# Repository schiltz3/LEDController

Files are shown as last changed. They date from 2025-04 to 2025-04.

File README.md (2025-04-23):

# Power Distribution Board Screenshots
Schematic:
[LEDControllerPDB/Outputs/LED Power Distribution Board sch.pdf](https://github.com/schiltz3/LEDController/blob/ab43750f7913fe42482215626bbdc119c35f3c25/LEDControllerPDB/Outputs/LED%20Power%20Distribution%20Board%20sch.pdf)
Front:
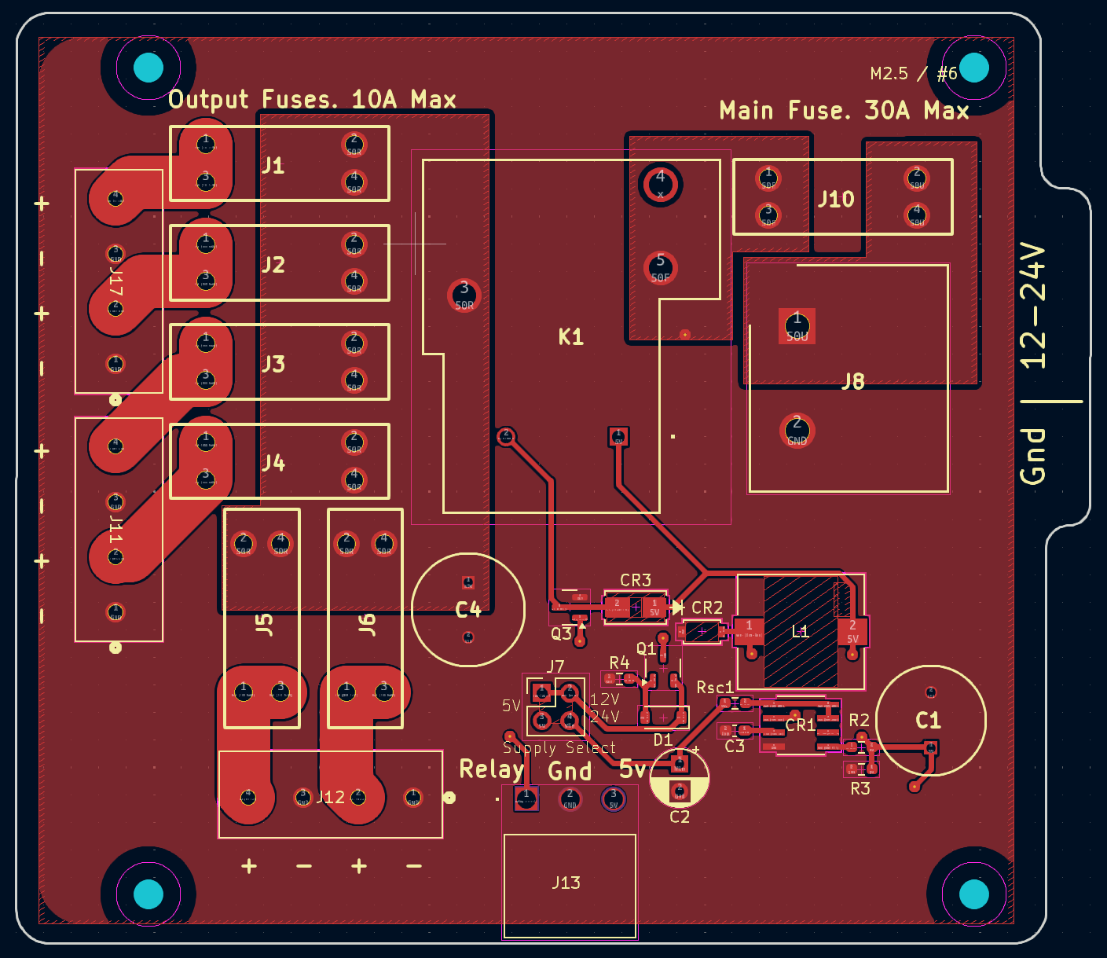
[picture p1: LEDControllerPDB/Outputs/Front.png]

Back:
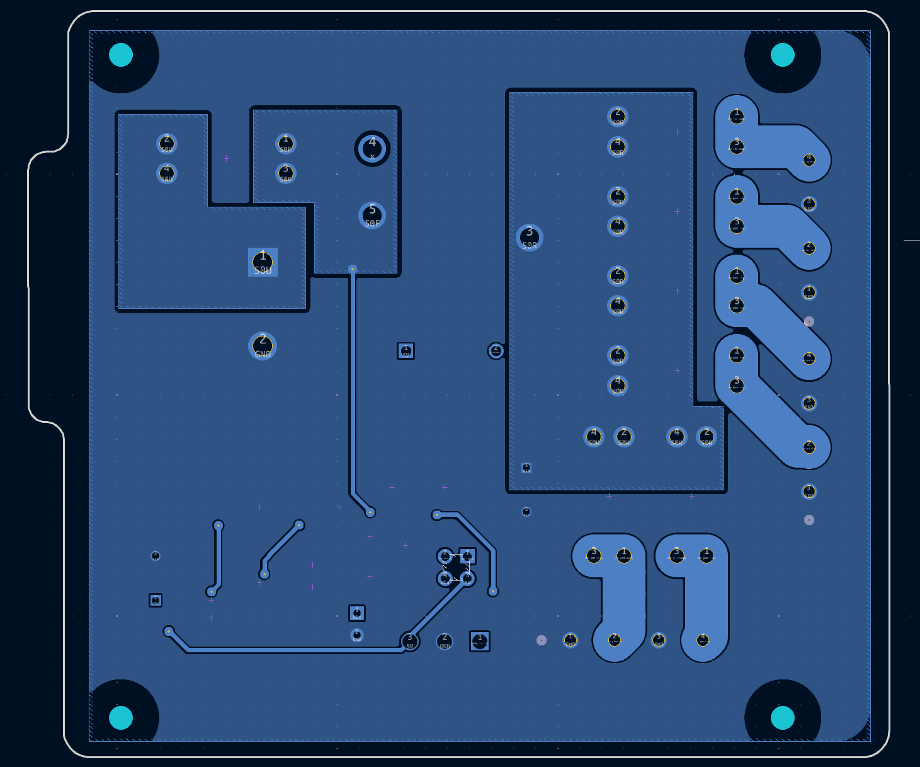
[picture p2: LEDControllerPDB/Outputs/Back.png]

All:
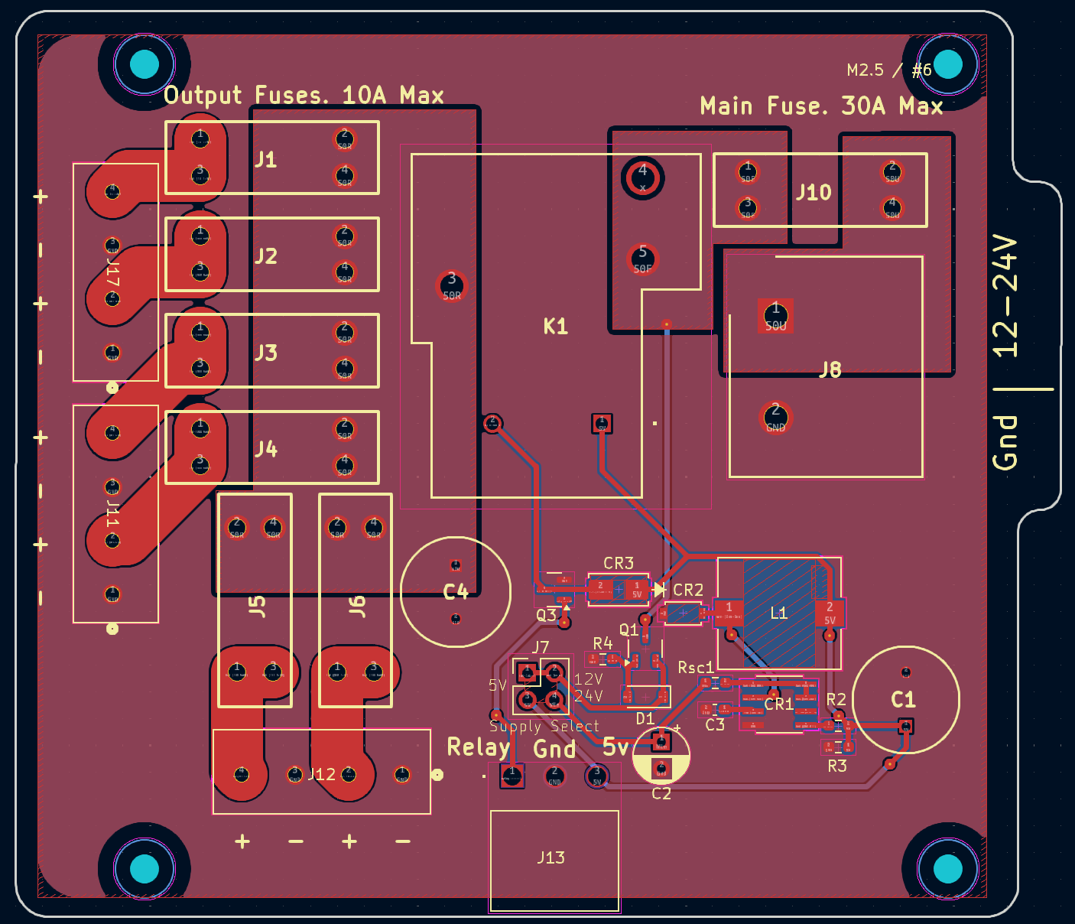
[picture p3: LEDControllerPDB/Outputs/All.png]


# Controll Board
Schematic:
[LEDControllerBrain/Outputs/LED Control Board sch.pdf](https://github.com/schiltz3/LEDController/blob/master/LEDControllerBrain/Outputs/LED%20Control%20Board%20sch.pdf)
Front:
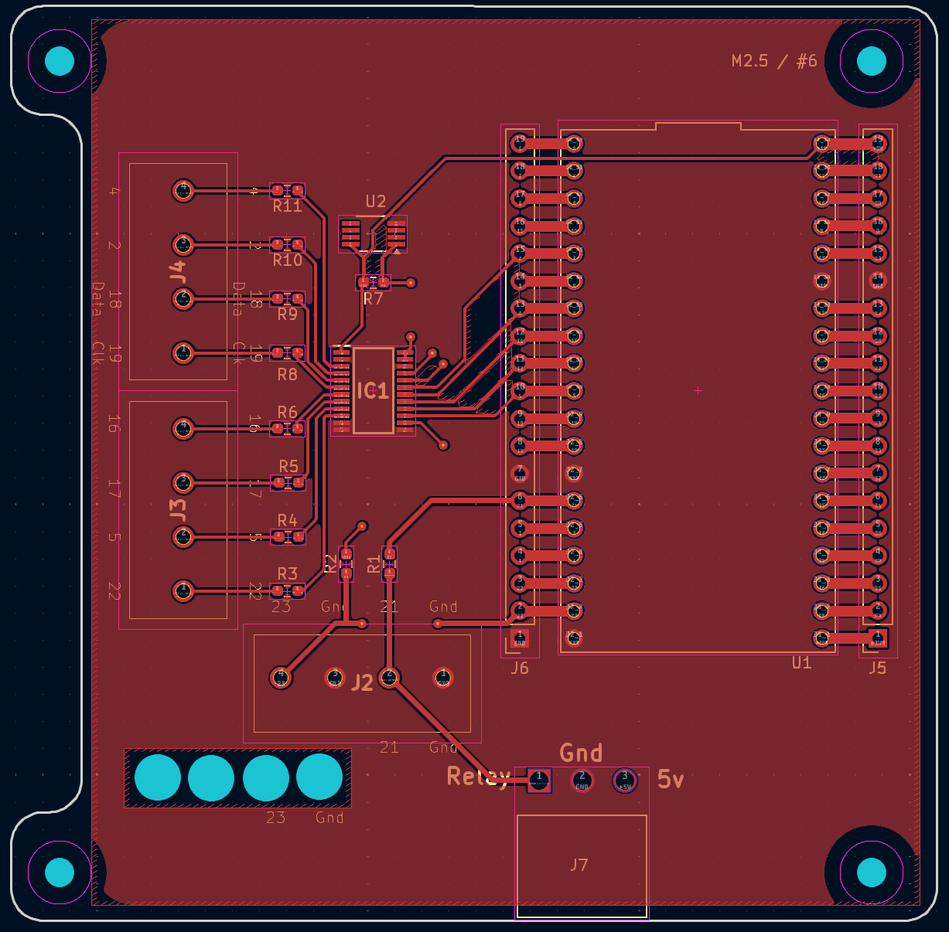
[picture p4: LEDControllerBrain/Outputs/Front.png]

Back:
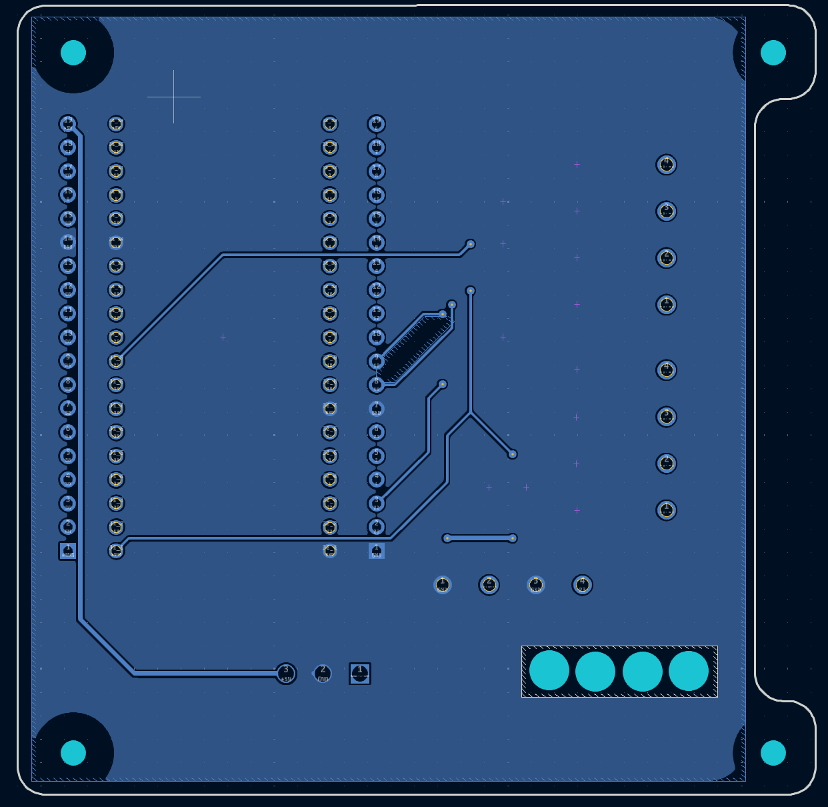
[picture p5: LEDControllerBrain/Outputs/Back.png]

All:
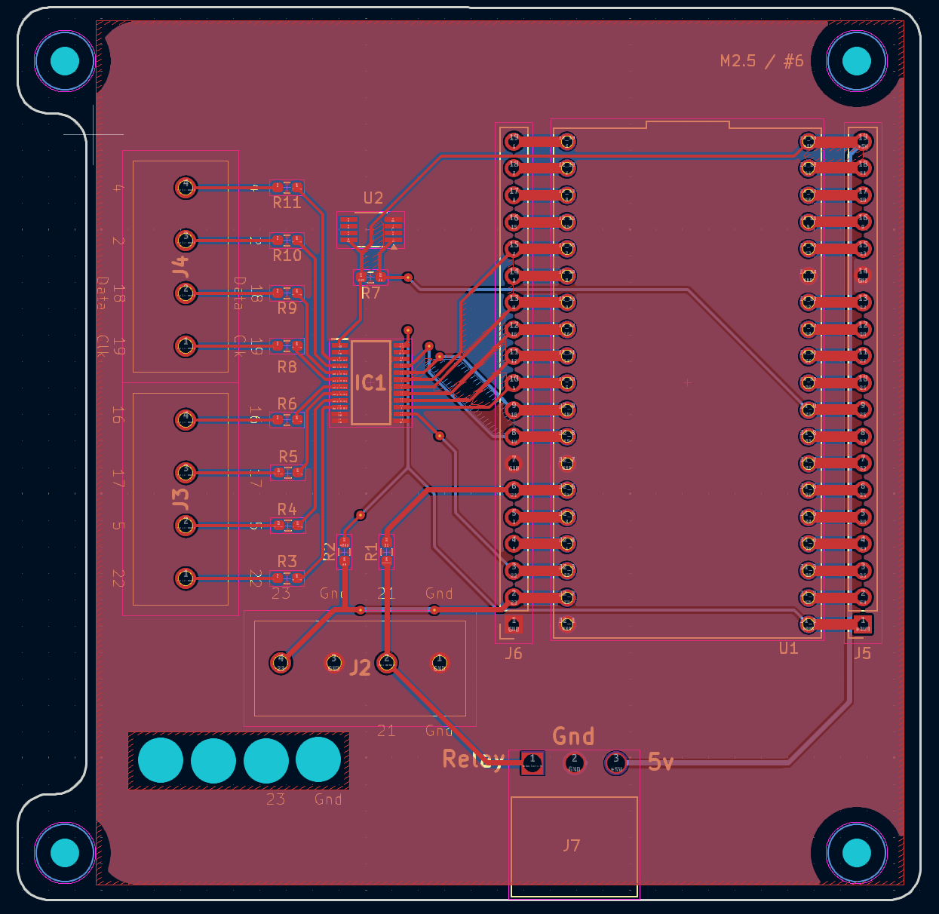
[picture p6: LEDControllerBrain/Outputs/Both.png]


# Assemmbly 
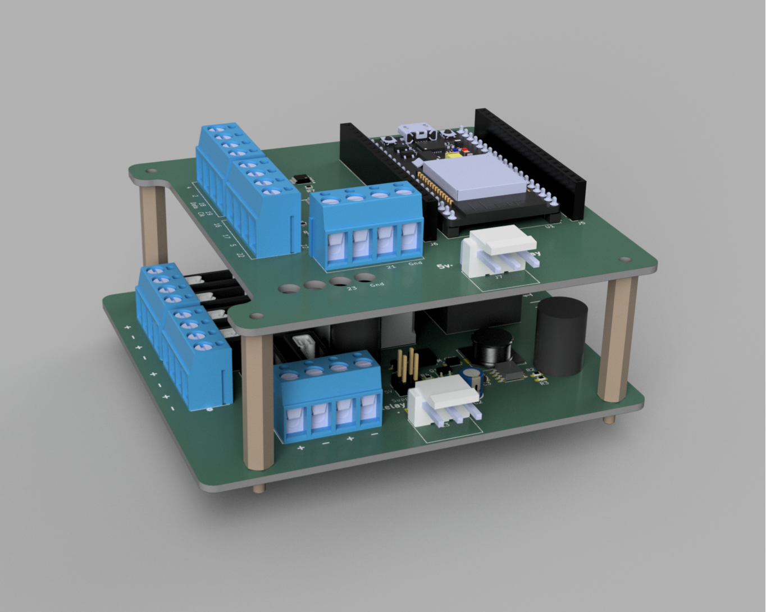
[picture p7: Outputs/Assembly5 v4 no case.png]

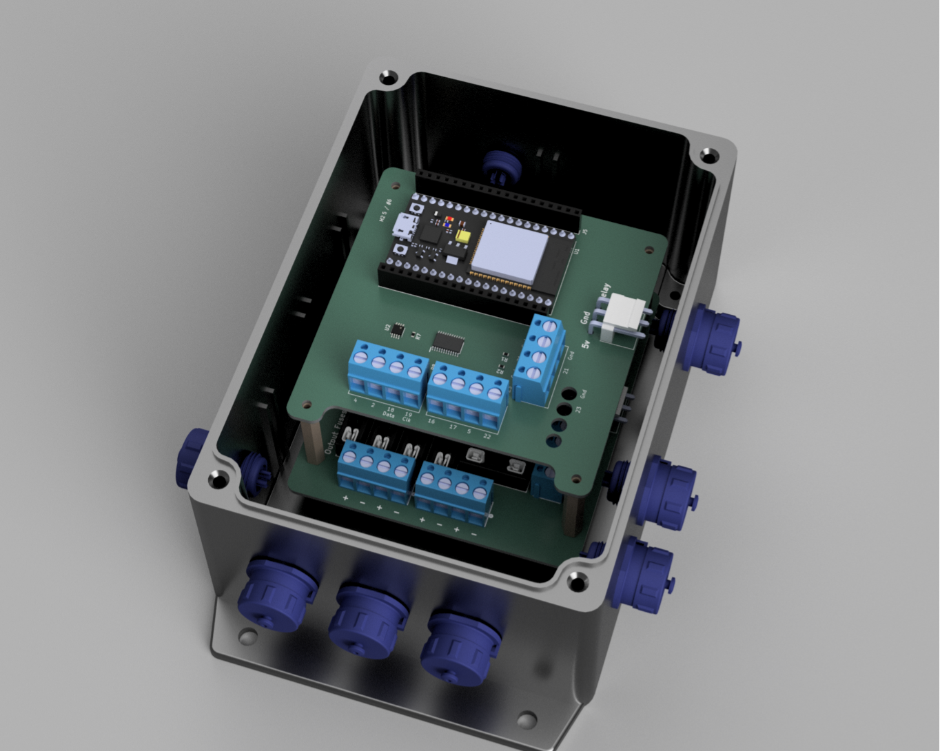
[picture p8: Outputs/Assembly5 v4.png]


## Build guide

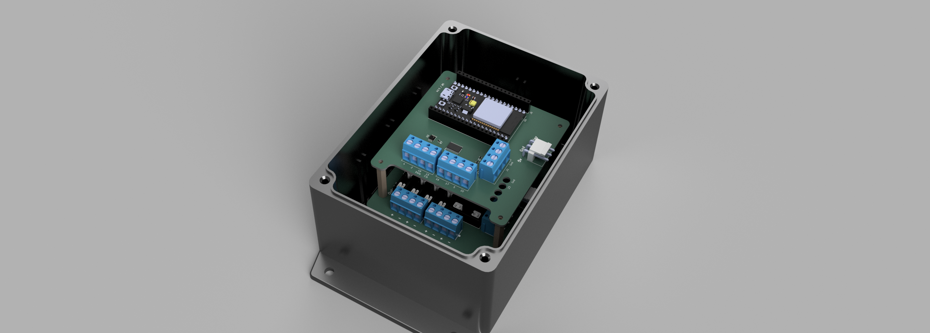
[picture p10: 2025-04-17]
LEDControllerBrain/Assembly5 v2.png

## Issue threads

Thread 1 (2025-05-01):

V2 improvements

schiltz3, 2025-05-01:
* Move to 1206 components
* Move to 1 fuse for 2 outputs
* Smaller bulk capacitor
* Smaller relay / remove relay and add a scheme for switching before the regulator
* Add test points to make reworking/testing IC's easier
* Smaller inter-pcb connectors

schiltz3, 2025-05-13:
Add a supervisor to the microcontroller to help it boot when the regulator has a bad slew rate

https://www.digikey.com/en/products/detail/texas-instruments/TLV809I50DBZR/2696416

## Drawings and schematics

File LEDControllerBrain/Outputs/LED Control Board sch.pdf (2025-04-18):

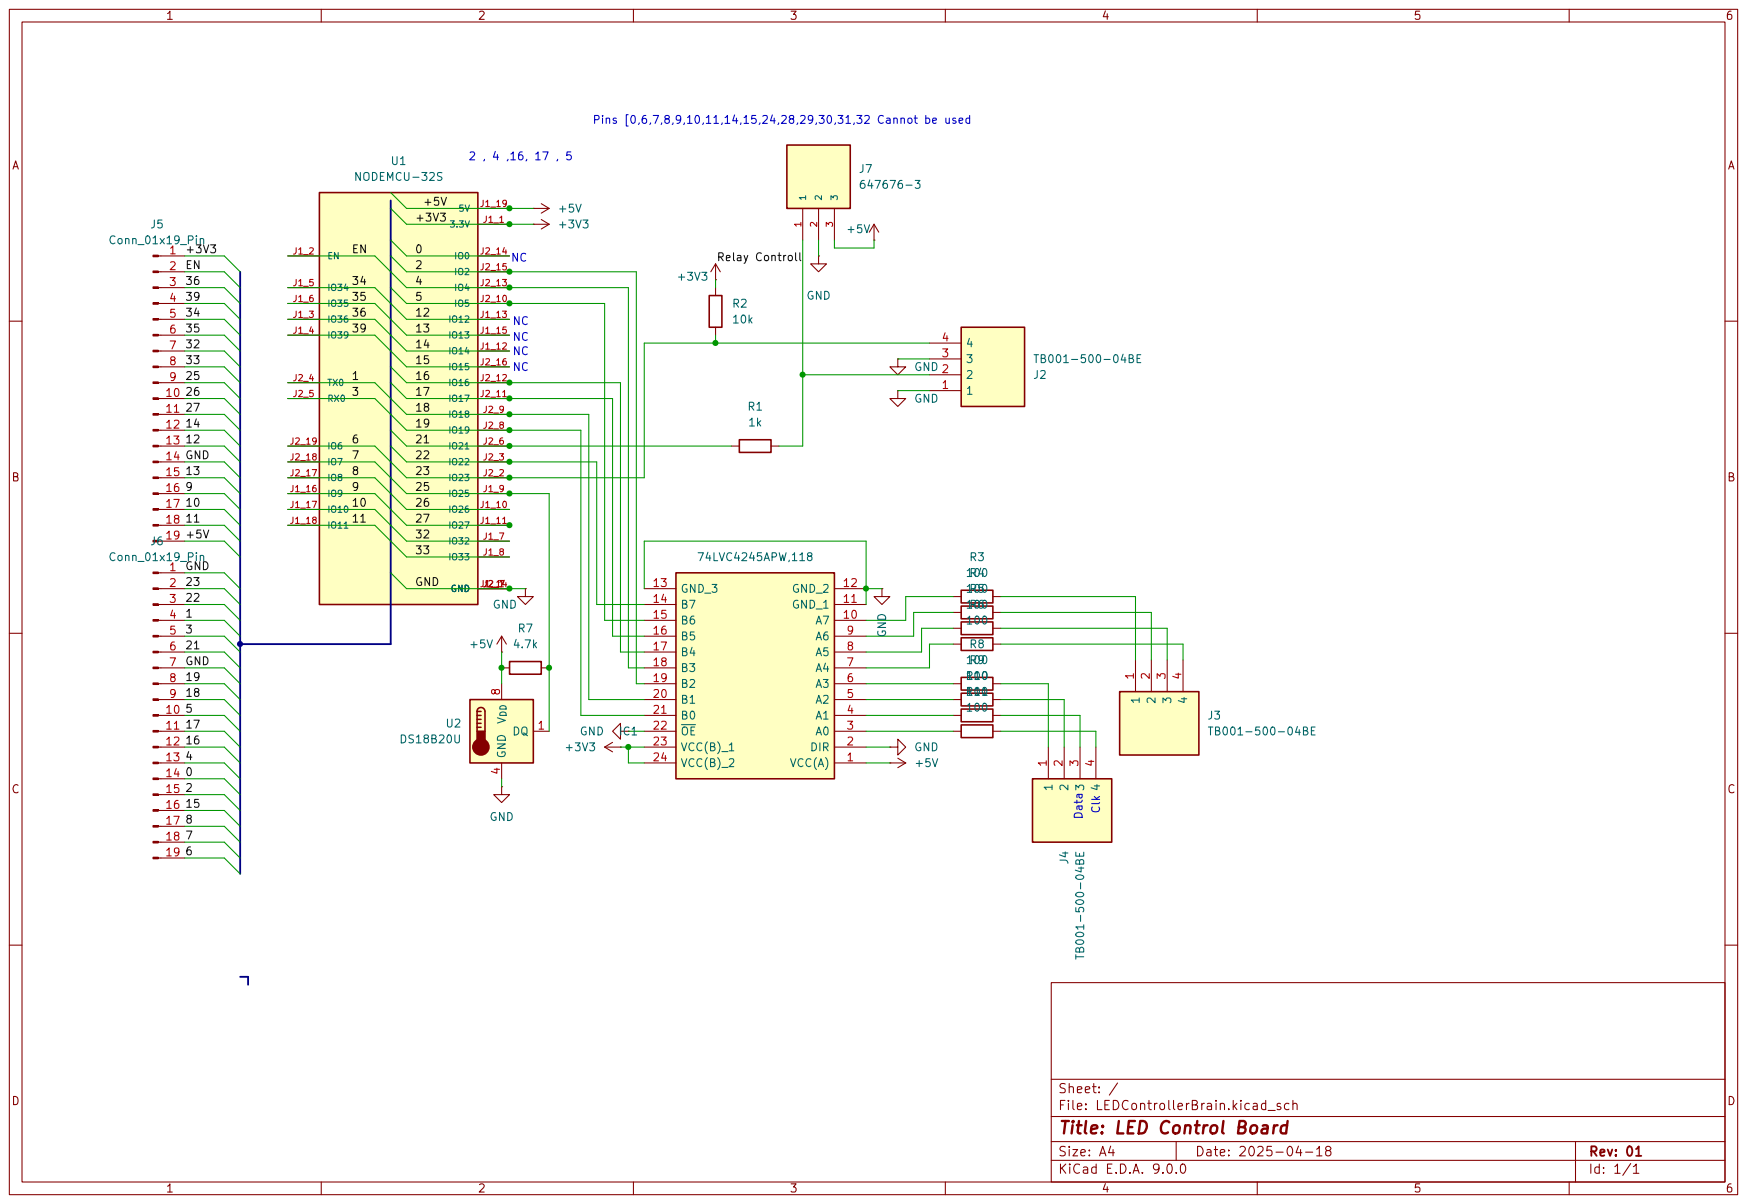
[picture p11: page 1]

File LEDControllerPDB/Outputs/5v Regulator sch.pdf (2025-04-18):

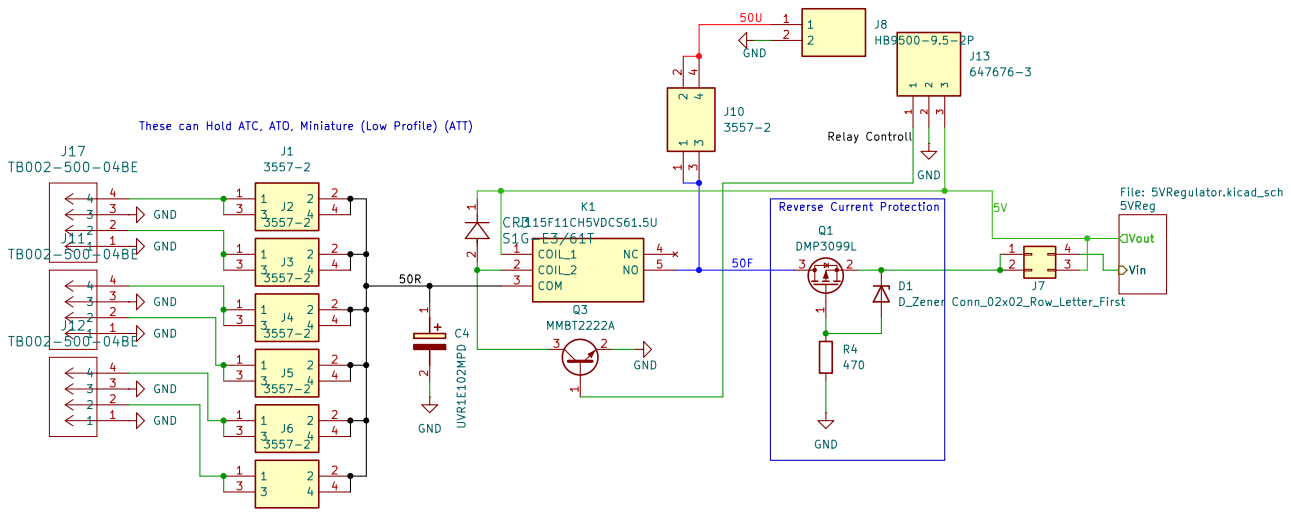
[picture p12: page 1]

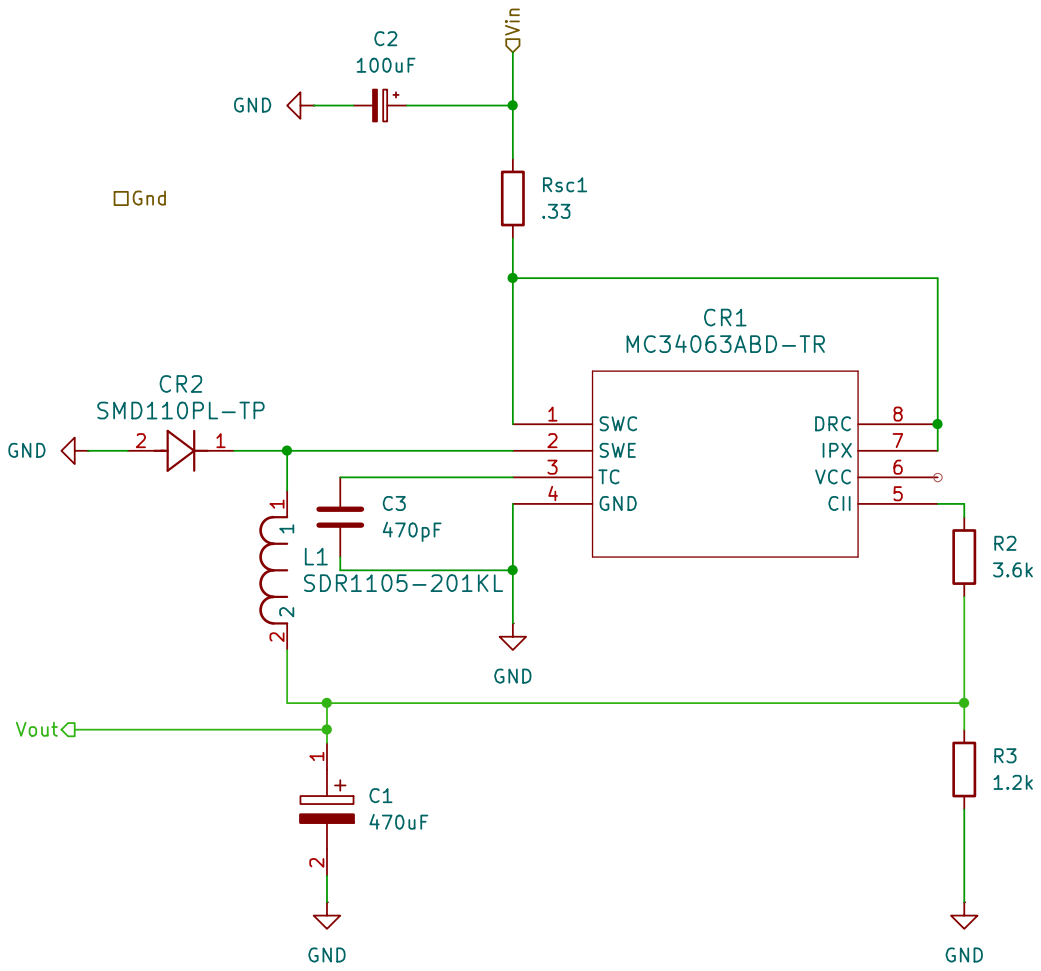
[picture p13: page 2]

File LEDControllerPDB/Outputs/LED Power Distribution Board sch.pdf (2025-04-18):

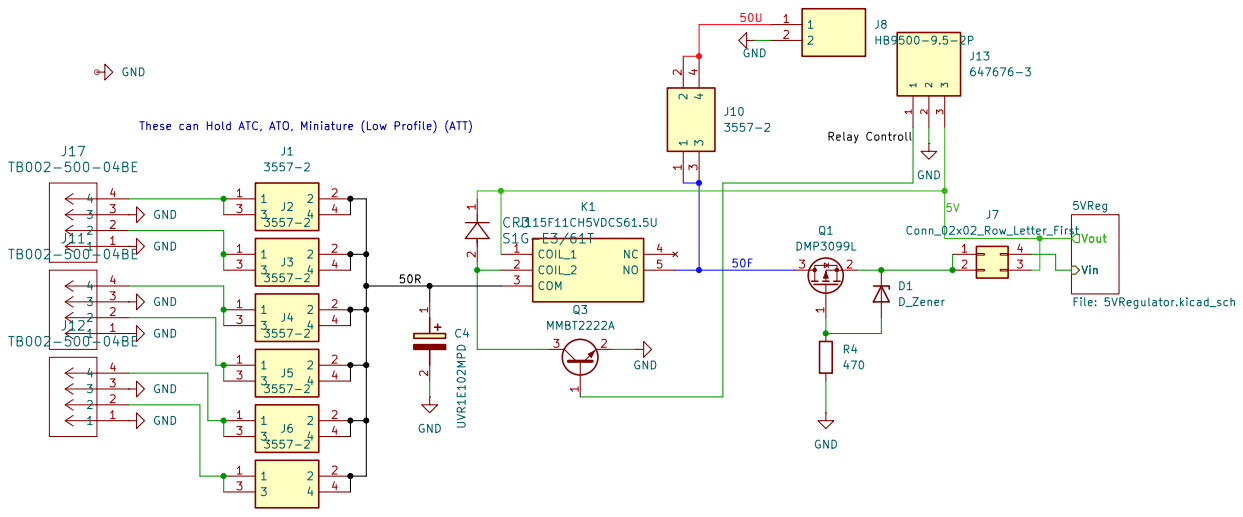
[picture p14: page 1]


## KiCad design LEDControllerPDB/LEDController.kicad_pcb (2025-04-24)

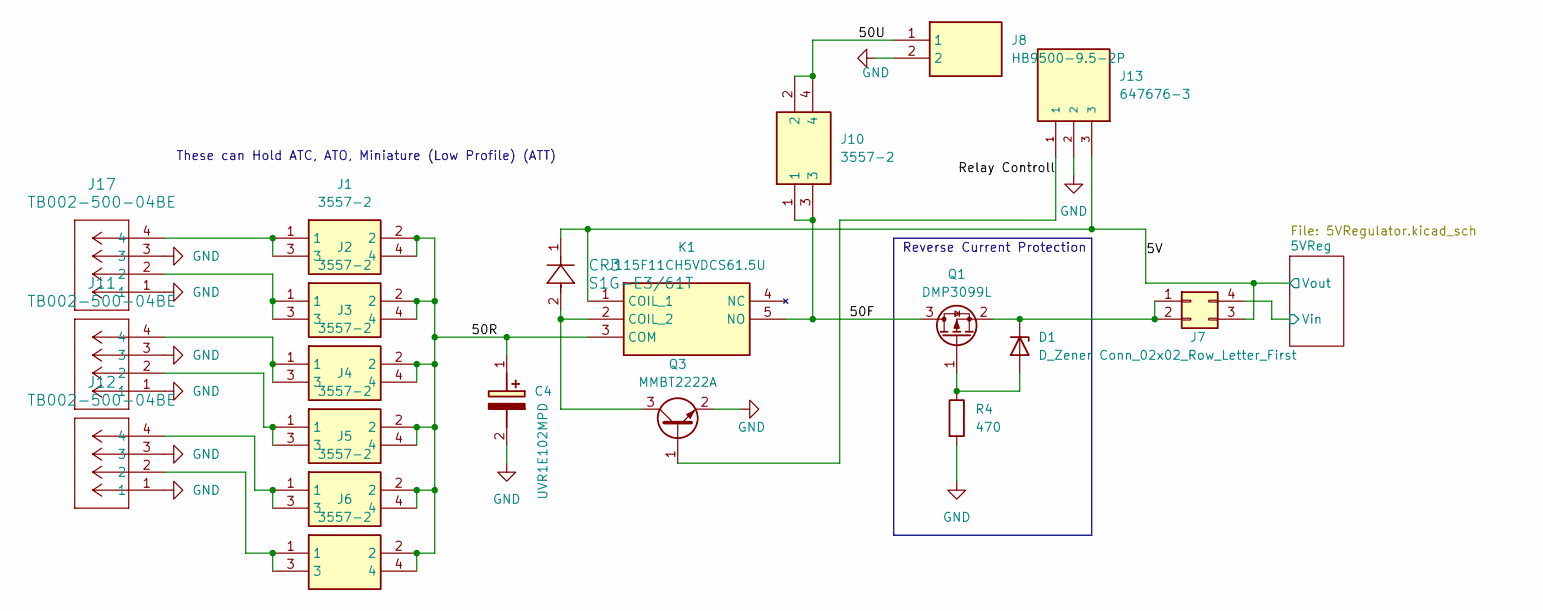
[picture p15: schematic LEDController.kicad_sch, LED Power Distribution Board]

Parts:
C4: UVR1E102MPD; CAPPRD500W60D1025H2200; Manufacturer_Part_Number UVR1E102MPD; Mouser Part Number 647-UVR1E102MPD
CR3: S1G-E3/61T; DIODE_DO214AC
D1: D_Zener; D_SOD-123
J1, J2, J3, J4, J5, J6, J10: 3557-2; Mouser Part Number 534-3557-2
J7: Conn_02x02_Row_Letter_First; PinHeader_2x02_P2.54mm_Vertical
J8: HB9500-9.5-2P; SHDR2W140P0X950_1X2_2055X1800X1440P; Manufacturer_Part_Number HB9500-9.5-2P
J11, J12, J17: TB002-500-04BE; CONN4_TB002-500_787x299_CUD
J13: 647676-3; TE_647676-3; PARTREV R
K1: J115F11CH5VDCS61.5U; J115F11CH5VDCS615U; Manufacturer_Part_Number J115F11CH5VDCS61.5U
Q1: DMP3099L; SOT-23-3
Q3: MMBT2222A; SOT-23
R4: 470; R_0603_1608Metric_Pad0.98x0.95mm_HandSolder

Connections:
/5V: CR3.1, J7.3, J13.3, K1.1 (COIL_1); also elsewhere on the board
/5VReg/Vin: J7.4; also elsewhere on the board
/50F: J10.1, J10.3, K1.5 (NO), Q1.3 (D)
/50R: C4.1 (+), J1.2, J1.4, J2.2, J2.4, J3.2, J3.4, J4.2, J4.4, J5.2, J5.4, J6.2, J6.4, K1.3 (COM)
/50U: J8.1, J10.2, J10.4
/Relay Controll: J13.1, Q3.1 (B)
GND: C4.2 (-), J8.2, J11.1, J11.3, J12.1, J12.3, J13.2, J17.1, J17.3, Q3.2 (E), R4.2; also elsewhere on the board
unnamed: D1.2 (A), Q1.1 (G), R4.1
unnamed: D1.1 (K), J7.1, J7.2, Q1.2 (S)
unnamed: J1.1, J1.3, J17.4
unnamed: J4.1, J4.3, J11.2
unnamed: J3.1, J3.3, J11.4
unnamed: J6.1, J6.3, J12.2
unnamed: J5.1, J5.3, J12.4
unnamed: J2.1, J2.3, J17.2
unnamed: CR3.2, K1.2 (COIL_2), Q3.3 (C)

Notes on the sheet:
Reverse Current Protection
These can Hold ATC, ATO, Miniature (Low Profile) (ATT)

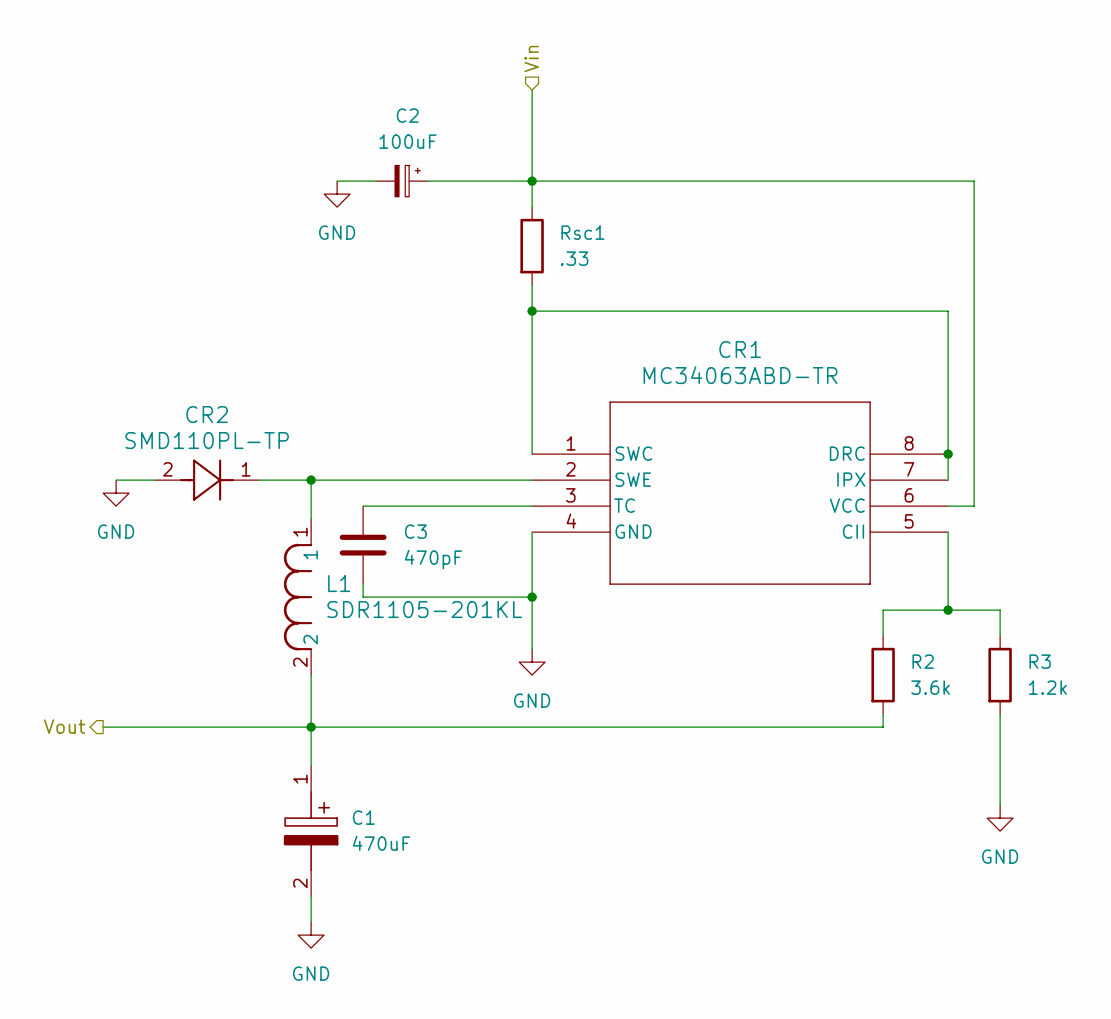
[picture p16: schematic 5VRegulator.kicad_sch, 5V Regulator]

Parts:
C1: 470uF; CAPPRD500W60D1000H1350; Manufacturer_Part_Number ESK477M025AH1EA; Mouser Part Number 80-ESK477M025AH1EA
C2: 100uF; CP_Radial_D5.0mm_P2.50mm
C3: 470pF; C_0603_1608Metric_Pad1.08x0.95mm_HandSolder
CR1: MC34063ABD-TR; SO-8_STM
CR2: SMD110PL-TP; SOD-123FL_MCC
L1: SDR1105-201KL; IND_BOURNS_SDR1105
R2: 3.6k; R_0603_1608Metric_Pad0.98x0.95mm_HandSolder
R3: 1.2k; R_0603_1608Metric_Pad0.98x0.95mm_HandSolder
Rsc1: .33; R_0603_1608Metric_Pad0.98x0.95mm_HandSolder

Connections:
/5V: C1.1, L1.2, R2.2; also elsewhere on the board
/5VReg/Vin: C2.1, CR1.6 (VCC), Rsc1.1; also elsewhere on the board
GND: C1.2, C2.2, C3.2, CR1.4 (GND), CR2.2, R3.2; also elsewhere on the board
unnamed: CR1.5 (CII), R2.1, R3.1
unnamed: CR1.1 (SWC), CR1.7 (IPX), CR1.8 (DRC), Rsc1.2
unnamed: CR1.2 (SWE), CR2.1, L1.1
unnamed: C3.1, CR1.3 (TC)

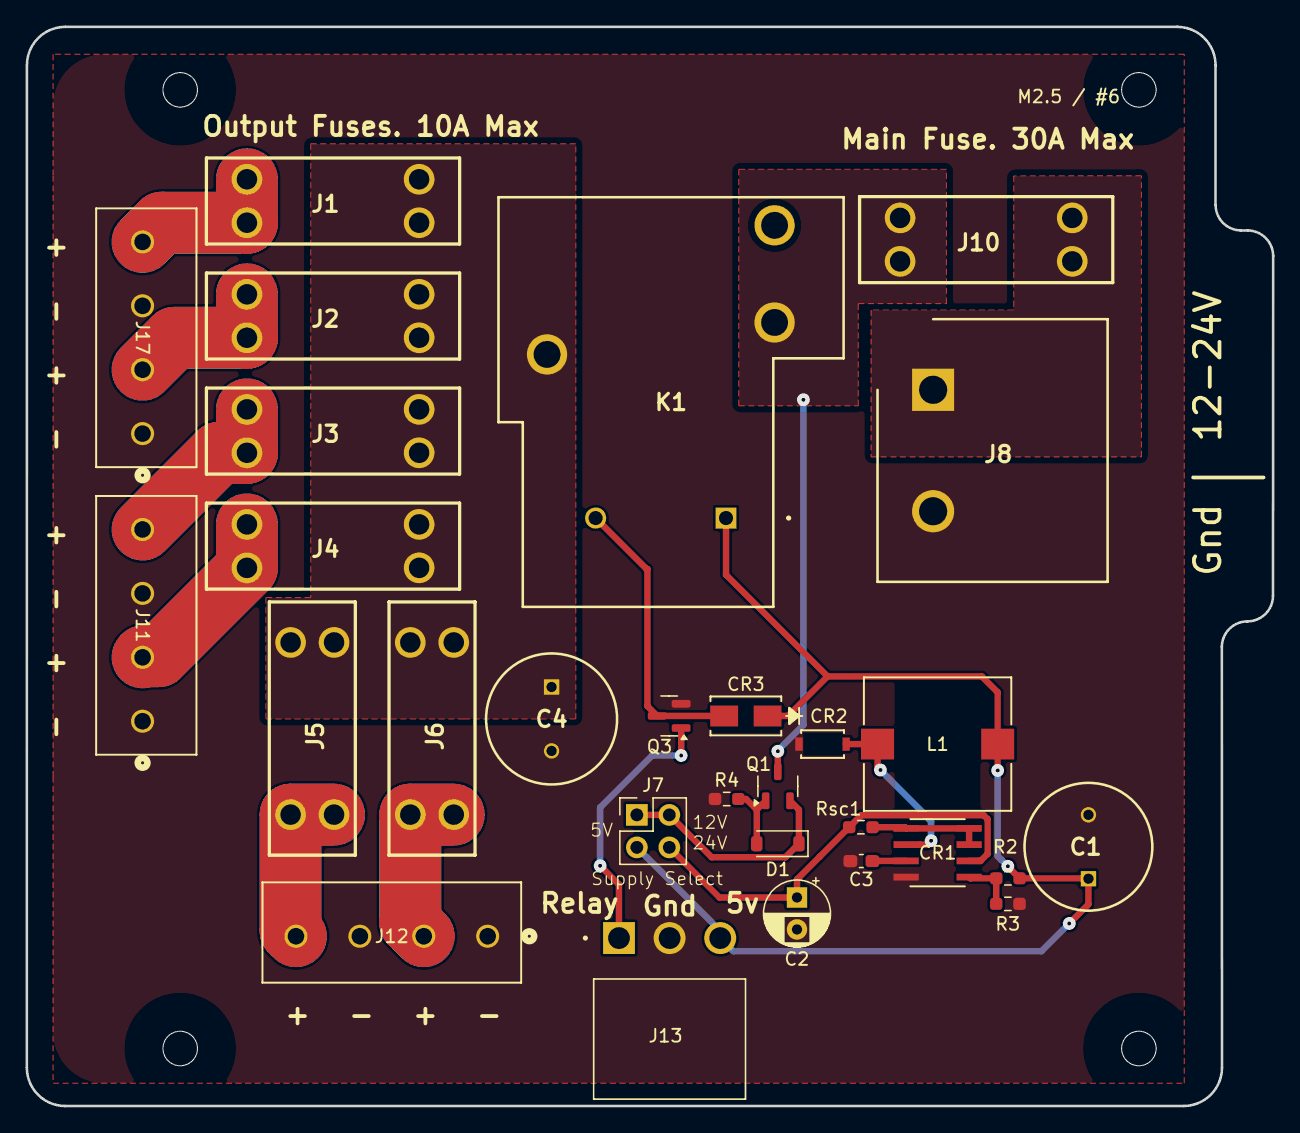
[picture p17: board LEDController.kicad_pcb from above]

Board: 2 copper layers, 97.5 x 84.4 mm, 30 parts (0 on the bottom side), 20 nets.

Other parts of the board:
M2.5 / #6: MountingHole_2.7mm_M2.5

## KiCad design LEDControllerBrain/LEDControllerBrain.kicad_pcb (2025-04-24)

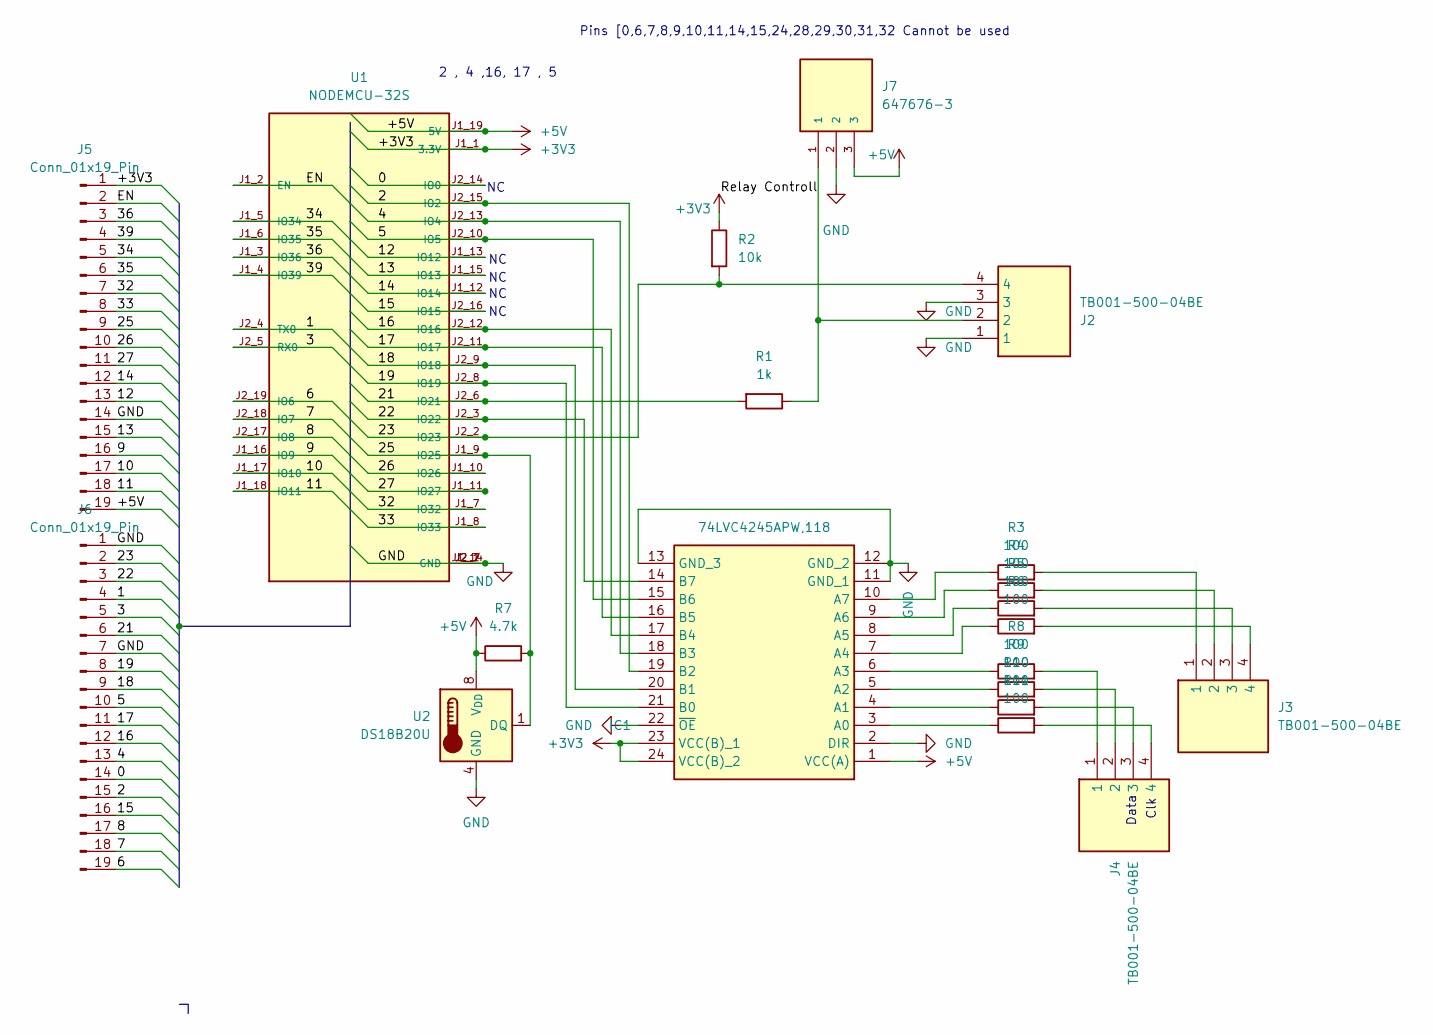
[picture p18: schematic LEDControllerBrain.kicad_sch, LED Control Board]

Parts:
IC1: 74LVC4245APW,118; SOP65P640X110-24N; Manufacturer_Part_Number 74LVC4245APW,118; Mouser Part Number 771-74LVC4245APW-T
J2, J3, J4: TB001-500-04BE; TB00150004BE; Manufacturer_Part_Number TB001-500-04BE
J5, J6: Conn_01x19_Pin; PinSocket_1x19_P2.54mm_Vertical
J7: 647676-3; TE_647676-3; PARTREV R
R1: 1k; R_0603_1608Metric_Pad0.98x0.95mm_HandSolder
R2: 10k; R_0603_1608Metric_Pad0.98x0.95mm_HandSolder
R3, R4, R5, R6, R8, R9, R10, R11: 100; R_0603_1608Metric_Pad0.98x0.95mm_HandSolder
R7: 4.7k; R_0603_1608Metric_Pad0.98x0.95mm_HandSolder
U1: NODEMCU-32S; MODULE_NODEMCU-32S; PARTREV V1
U2: DS18B20U; MSOP-8_3x3mm_P0.65mm

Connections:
+5V: IC1.1 (VCC(A)), J5.19, J7.3, R7.1, U1.J1_19 (5V), U2.8 (V_{DD})
/0: J6.14, U1.J2_14 (IO0)
/1: J6.4, U1.J2_4 (TX0)
/2: IC1.19 (B2), J6.15, U1.J2_15 (IO2)
/3: J6.5, U1.J2_5 (RX0)
/4: IC1.18 (B3), J6.13, U1.J2_13 (IO4)
/5: IC1.15 (B6), J6.10, U1.J2_10 (IO5)
/6: J6.19, U1.J2_19 (IO6)
/7: J6.18, U1.J2_18 (IO7)
/8: J6.17, U1.J2_17 (IO8)
/9: J5.16, U1.J1_16 (IO9)
/10: J5.17, U1.J1_17 (IO10)
/11: J5.18, U1.J1_18 (IO11)
/12: J5.13, U1.J1_13 (IO12)
/13: J5.15, U1.J1_15 (IO13)
/14: J5.12, U1.J1_12 (IO14)
/15: J6.16, U1.J2_16 (IO15)
/16: IC1.17 (B4), J6.12, U1.J2_12 (IO16)
/17: IC1.16 (B5), J6.11, U1.J2_11 (IO17)
/18: IC1.20 (B1), J6.9, U1.J2_9 (IO18)
/19: IC1.21 (B0), J6.8, U1.J2_8 (IO19)
/21: J6.6, R1.2, U1.J2_6 (IO21)
/22: IC1.14 (B7), J6.3, U1.J2_3 (IO22)
/25: J5.9, R7.2, U1.J1_9 (IO25), U2.1 (DQ)
/26: J5.10, U1.J1_10 (IO26)
/27: J5.11, U1.J1_11 (IO27)
/32: J5.7, U1.J1_7 (IO32)
/33: J5.8, U1.J1_8 (IO33)
/34: J5.5, U1.J1_5 (IO34)
/35: J5.6, U1.J1_6 (IO35)
/36: J5.3, U1.J1_3 (IO36)
/39: J5.4, U1.J1_4 (IO39)
/EN: J5.2, U1.J1_2 (EN)
/Relay Controll: J2.2, J7.1, R1.1
GND: IC1.2 (DIR), IC1.11 (GND_1), IC1.12 (GND_2), IC1.13 (GND_3), IC1.22 (~OE), J2.1, J2.3, J5.14, J6.1, J6.7, J7.2, U1.J1_14 (GND), U1.J2_1 (GND), U1.J2_7 (GND), U2.4 (GND)
unnamed: IC1.3 (A0), R11.1
unnamed: IC1.4 (A1), R10.1
unnamed: IC1.5 (A2), R9.1
unnamed: IC1.6 (A3), R8.1
unnamed: IC1.7 (A4), R6.1
unnamed: IC1.8 (A5), R5.1
unnamed: IC1.9 (A6), R4.1
unnamed: IC1.10 (A7), R3.1
unnamed: J3.1, R3.2
unnamed: J3.2, R4.2
unnamed: J3.3, R5.2
unnamed: J3.4, R6.2
unnamed: J4.1, R8.2
unnamed: J4.2, R9.2
unnamed: J4.3, R10.2
unnamed: J4.4, R11.2

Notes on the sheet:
Pins [0,6,7,8,9,10,11,14,15,24,28,29,30,31,32 Cannot be used
2 , 4 ,16, 17 , 5
Data
Clk

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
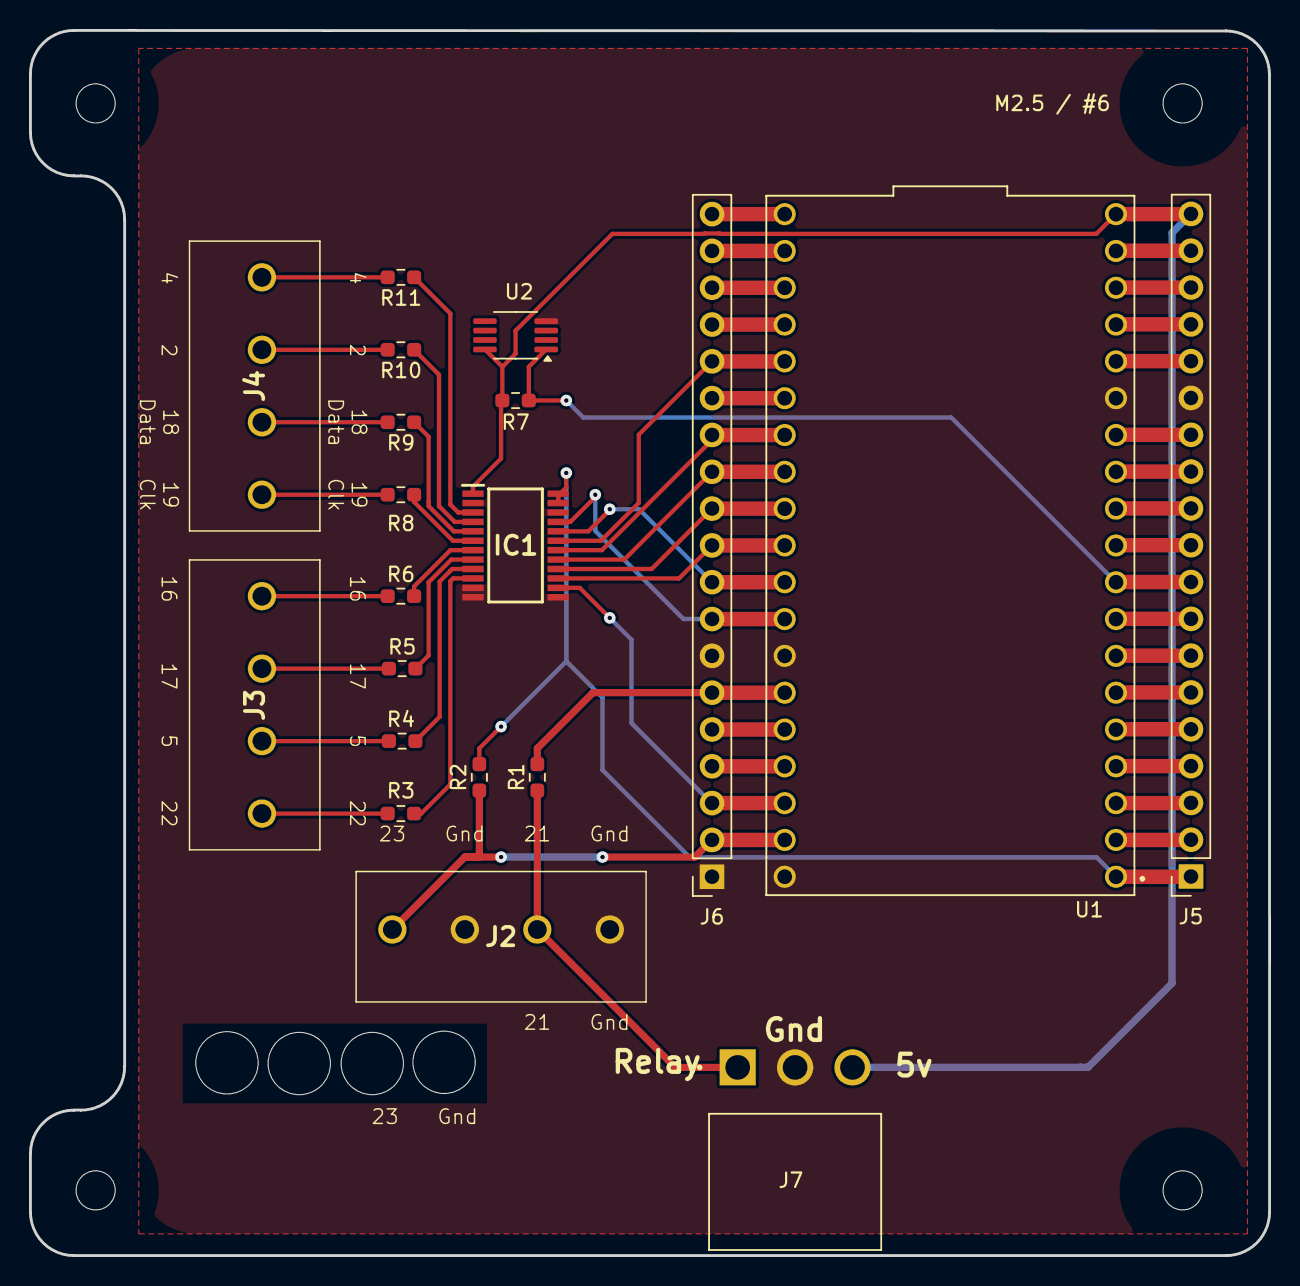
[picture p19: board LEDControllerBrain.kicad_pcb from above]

Board: 2 copper layers, 85.5 x 84.5 mm, 21 parts (0 on the bottom side), 53 nets.

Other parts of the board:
M2.5 / #6: MountingHole_2.7mm_M2.5

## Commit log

2024-12-22 Added diode and transistor
    [LEDController.kicad_pcb, LEDController.kicad_sch]
2024-12-23 Added screw terminals
    [LEDController.kicad_sch]
2024-12-23 updated pcb
    [LEDController.kicad_pcb]
2024-12-23 Added new high current terminal
    [LEDController.kicad_pcb, LEDController.kicad_sch]
2024-12-24 final schematic
    [LEDController.kicad_pcb, LEDController.kicad_sch]
2024-12-27 add footprints from laptop
    [LEDController.kicad_pcb]
2024-12-27 wip layout
    [LEDController.kicad_pcb, LEDController.kicad_sch]
2024-12-27 add schematic and footprints
2024-12-27 laptop footprints and sch
2024-12-30 Final Layout
    [LEDController.kicad_pcb]
2025-02-01 add nodemcu
    [LEDControllerBrain.kicad_sch]
2025-04-07 Add new footprints
2025-04-07 add 24v support and reverse voltage protection
    [5VRegulator.kicad_sch, LEDController.kicad_pcb, LEDController.kicad_sch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]
2025-04-08 hand solder
    [LEDController.kicad_sch]
2025-04-09 finished pdb
    [LEDController.kicad_pcb, LEDControllerBrain.kicad_sch]
2025-04-18 generate outputs
    [LEDController.kicad_sch, LEDControllerBrain.kicad_sch]
2025-04-21 add name
    [5VRegulator.kicad_sch]
2025-04-22 fix regulator
    [5VRegulator.kicad_sch, LEDController.kicad_pcb]
2025-04-24 increase pad size
    [LEDController.kicad_pcb, LEDControllerBrain.kicad_pcb]
